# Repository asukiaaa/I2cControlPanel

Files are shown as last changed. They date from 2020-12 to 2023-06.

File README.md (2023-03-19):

# I2cControlPanel

A wired control panel.

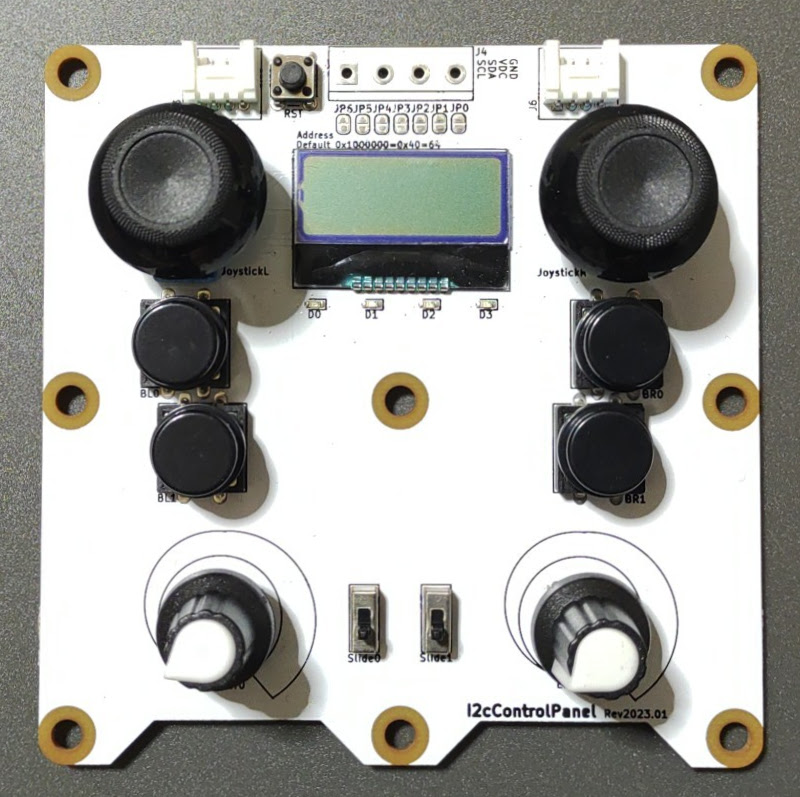
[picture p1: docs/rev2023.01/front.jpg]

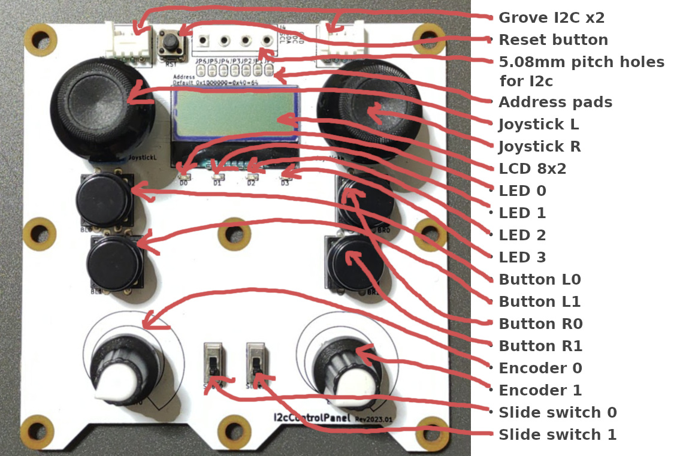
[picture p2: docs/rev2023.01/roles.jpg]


# Where to buy

- [I2cControlPanel | スイッチサイエンス](https://www.switch-science.com/catalog/6824/)

# Library
[I2cControlPanel_asukiaaa](https://github.com/asukiaaa/I2cControlPanel_asukiaaa)

# Components

- [ATmega328PB-MU](https://www.digikey.jp/product-detail/ja/microchip-technology/ATMEGA328PB-MUR/ATMEGA328PB-MURCT-ND/5722708)
- [PS4 joy stick](https://ja.aliexpress.com/item/1005001729380060.html)
- [PS4 joy stick cap](https://ja.aliexpress.com/item/32964247181.html)
- [THT encoder](https://ja.aliexpress.com/item/1005001556801559.html)
- [Switch 12mm black](https://akizukidenshi.com/catalog/g/gP-09826/)
- [LCD 8x2](https://akizukidenshi.com/catalog/g/gP-06669/)
- [Slide switch](https://akizukidenshi.com/catalog/g/gP-12723/)
- [3V3 regulator](https://akizukidenshi.com/catalog/g/gI-10675/)
- [LED 0603 green](https://akizukidenshi.com/catalog/g/gI-06417/)
- [0.47uf 0402](https://akizukidenshi.com/catalog/g/gP-07504/)
- [0.01uf 0603](https://akizukidenshi.com/catalog/g/gP-13387/)
- 0.1uf 0603
- [Diode array](https://www.digikey.jp/product-detail/ja/toshiba-semiconductor-and-storage/1SS309-TE85L-F/1SS309-TE85LF-CT-ND/4304019)
- 10k 0603

# Old components

- [Panel mount encoder](https://ja.aliexpress.com/item/32783863247.html)
- [Low height joystick](https://ja.aliexpress.com/item/4000540937190.html)
- [Low height joystick cap](https://ja.aliexpress.com/item/33035062962.html)
- [Diode](https://akizukidenshi.com/catalog/g/gI-06467/)

# License

MIT

# References

- [エンコーダー（可変抵抗）が付いた有線コントローラーを作ってみた](https://asukiaaa.blogspot.com/2020/11/i2c-control-panel.html)
- [WiredController](https://github.com/asukiaaa/WiredControllerPcb)

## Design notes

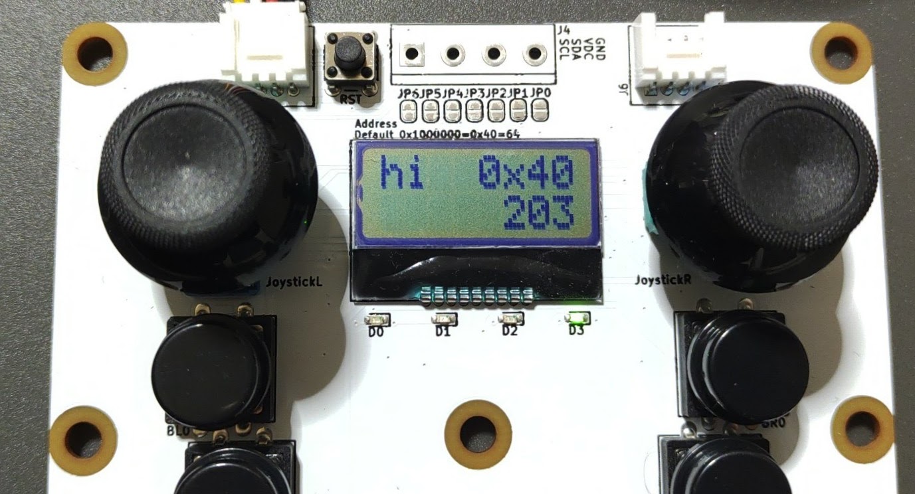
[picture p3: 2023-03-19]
docs/rev2023.01/lcd_and_leds.jpg

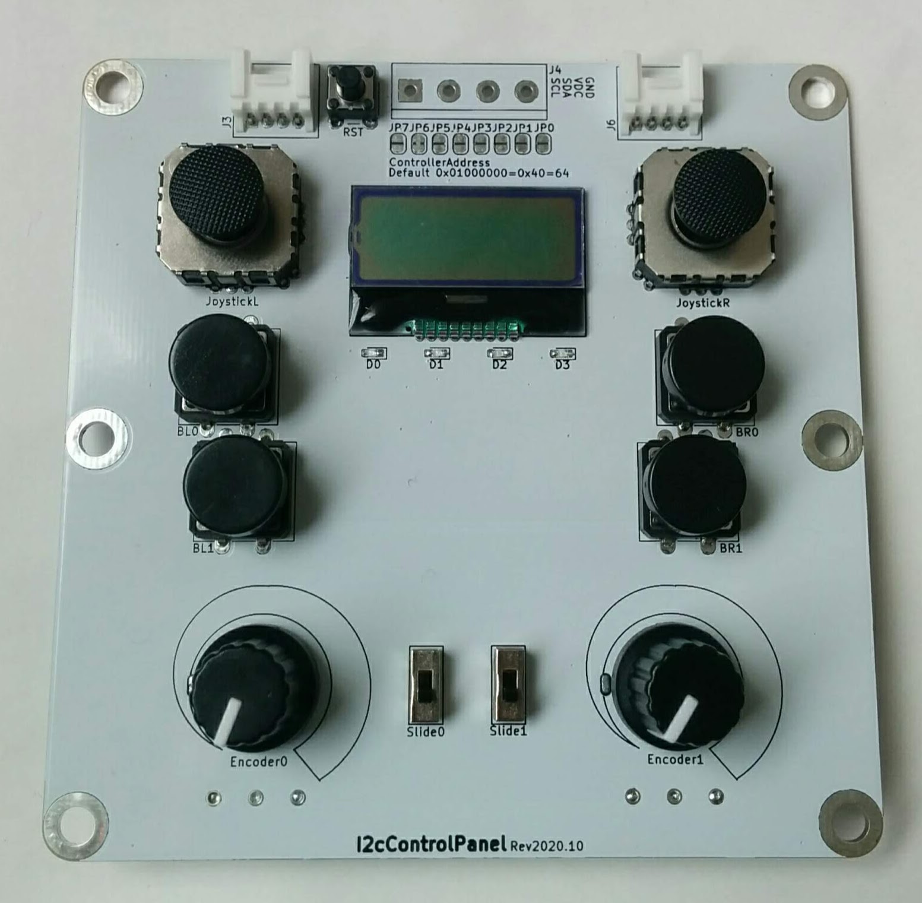
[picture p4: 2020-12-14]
docs/rev2020.10/I2cControlPanel.jpg

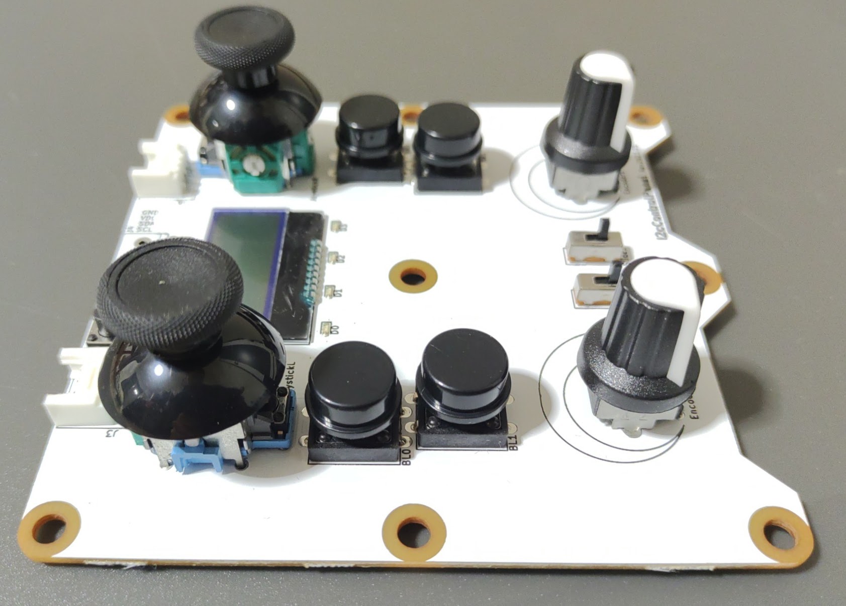
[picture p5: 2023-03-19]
docs/rev2023.01/side_view.jpg

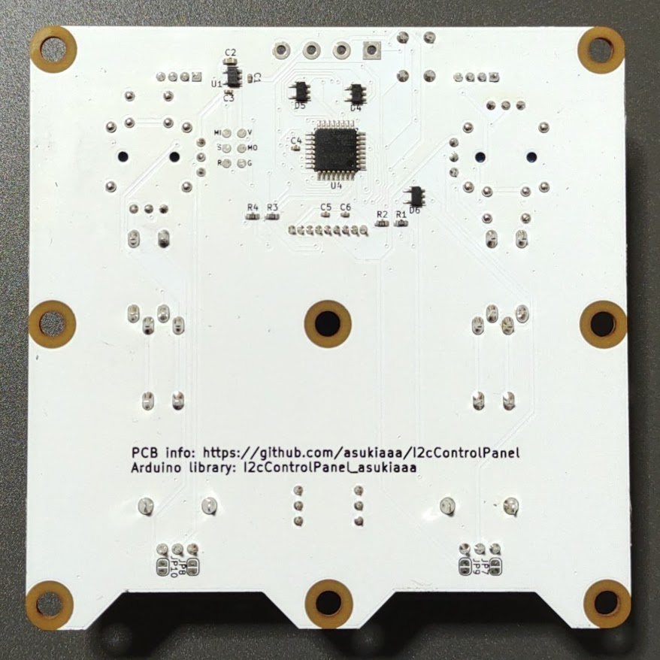
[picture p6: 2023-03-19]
docs/rev2023.01/back.jpg

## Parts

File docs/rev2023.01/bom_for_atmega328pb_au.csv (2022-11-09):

Reference | Quantity | Value | Footprint | url | memo
BL0 BR0 BL1 BR1 | 4 | Push switch 12mm black | footprints:SW_Center_PUSH-12mm |  | 12mm black
C2 | 1 | 10n | Capacitor_SMD:C_0603_1608Metric |  | 0.01uf 0603inch more than 10V. I don’t mind vendor
C3 | 1 | 0.47u | Capacitor_SMD:C_0402_1005Metric |  | 0.47uf 0402inch more than 10V. I don’t mind vendor
C1 C4 C5 C6 | 4 | 0.1u | Capacitor_SMD:C_0402_1005Metric |  | 0.1uf 0402inch more than 10V. I don’t mind vendor
D0 D1 D2 D3 | 4 | LED green 0603 inch | Diode_SMD:D_0603_1608Metric_Pad1.05x0.95mm_HandSolder | https://akizukidenshi.com/catalog/g/gI-06417/
D4 D5 D6 | 3 | 1SS309 | asukiaaa-kicad-footprints:SC-74-5_1.6x2.9mm_P0.95mm | https://www.digikey.jp/product-detail/ja/toshiba-semiconductor-and-storage/1SS309-TE85L-F/1SS309-TE85LF-CT-ND/4304019
Encoder0 Encoder1 | 2 | Encoder 10k | asukiaaa-kicad-footprints:RoteryEncoderWithPowerLabel | https://ja.aliexpress.com/item/1005001556801559.html
J1 J5 | 1 | Joystick | asukiaaa-kicad-footprints:PS4tJoystick | https://ja.aliexpress.com/item/1005001729380060.html
J3 J6 | 2 | Conn_01x04 | footprints:NS-Tech_Grove_1x04_P2mm_Horizontal | https://www.seeedstudio.com/Grove-Universal-4-pin-connector-90-10-PCs.html | Grove horizontal connector
R1 R2 R3 R4 | 4 | 100k | Resistor_SMD:R_0603_1608Metric |  | 100k 0603inch. I don’t mind vendor
SW6 | 1 | Push switch 6mm black | Button_Switch_THT:SW_PUSH_6mm |  | 6mm black
Slide0 Slide1 | 2 | SlideSwitch | asukiaaa-kicad-footprints:SlideSwitch_SS12D01G4_2posi_1line | https://akizukidenshi.com/catalog/g/gP-12723/
U1 | 1 | NJM12888F33 | Package_TO_SOT_SMD:SOT-23-5 | https://akizukidenshi.com/catalog/g/gI-10675/
U4 | 1 | ATmega328PB-A | asukiaaa-kicad-footprints:TQFP-32_7x7mm_P0.8mm_short_inner | https://www.lcsc.com/product-detail/Microcontroller-Units-MCUs-MPUs-SOCs_Microchip-Tech-ATMEGA328PB-AU_C132230.html
U3 | 1 | AQM0802 | asukiaaa-kicad-footprints:AQM0802A-RN-GBW | https://akizukidenshi.com/catalog/g/gP-06669/

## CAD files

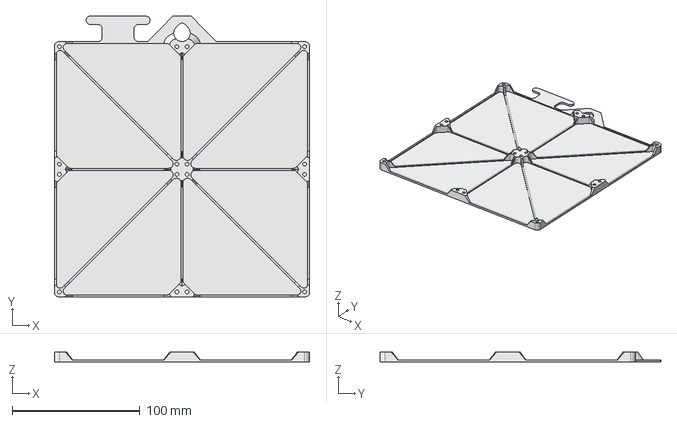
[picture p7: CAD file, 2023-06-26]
models/frame_2x2/frame_2x2.FCStd
200.0 x 220.0 x 8.00 mm

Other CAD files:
models/frame_2x2/frame_2x2.stl

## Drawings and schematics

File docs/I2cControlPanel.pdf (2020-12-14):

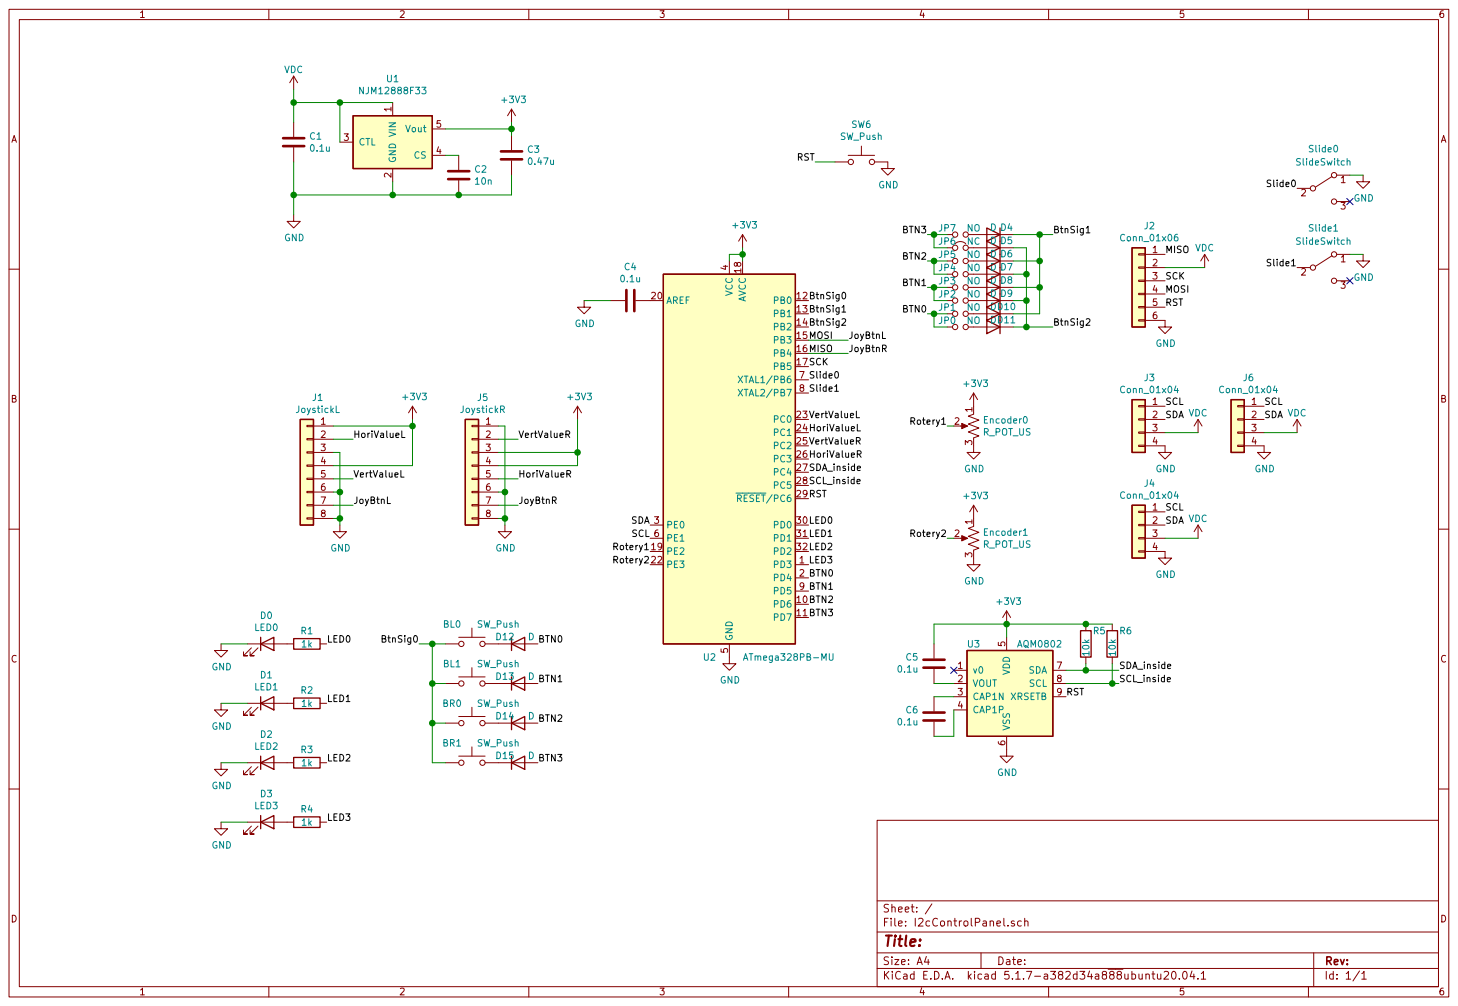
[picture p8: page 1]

Id: 1/1 Title: File: I2cControlPanel.sch Sheet: / R3

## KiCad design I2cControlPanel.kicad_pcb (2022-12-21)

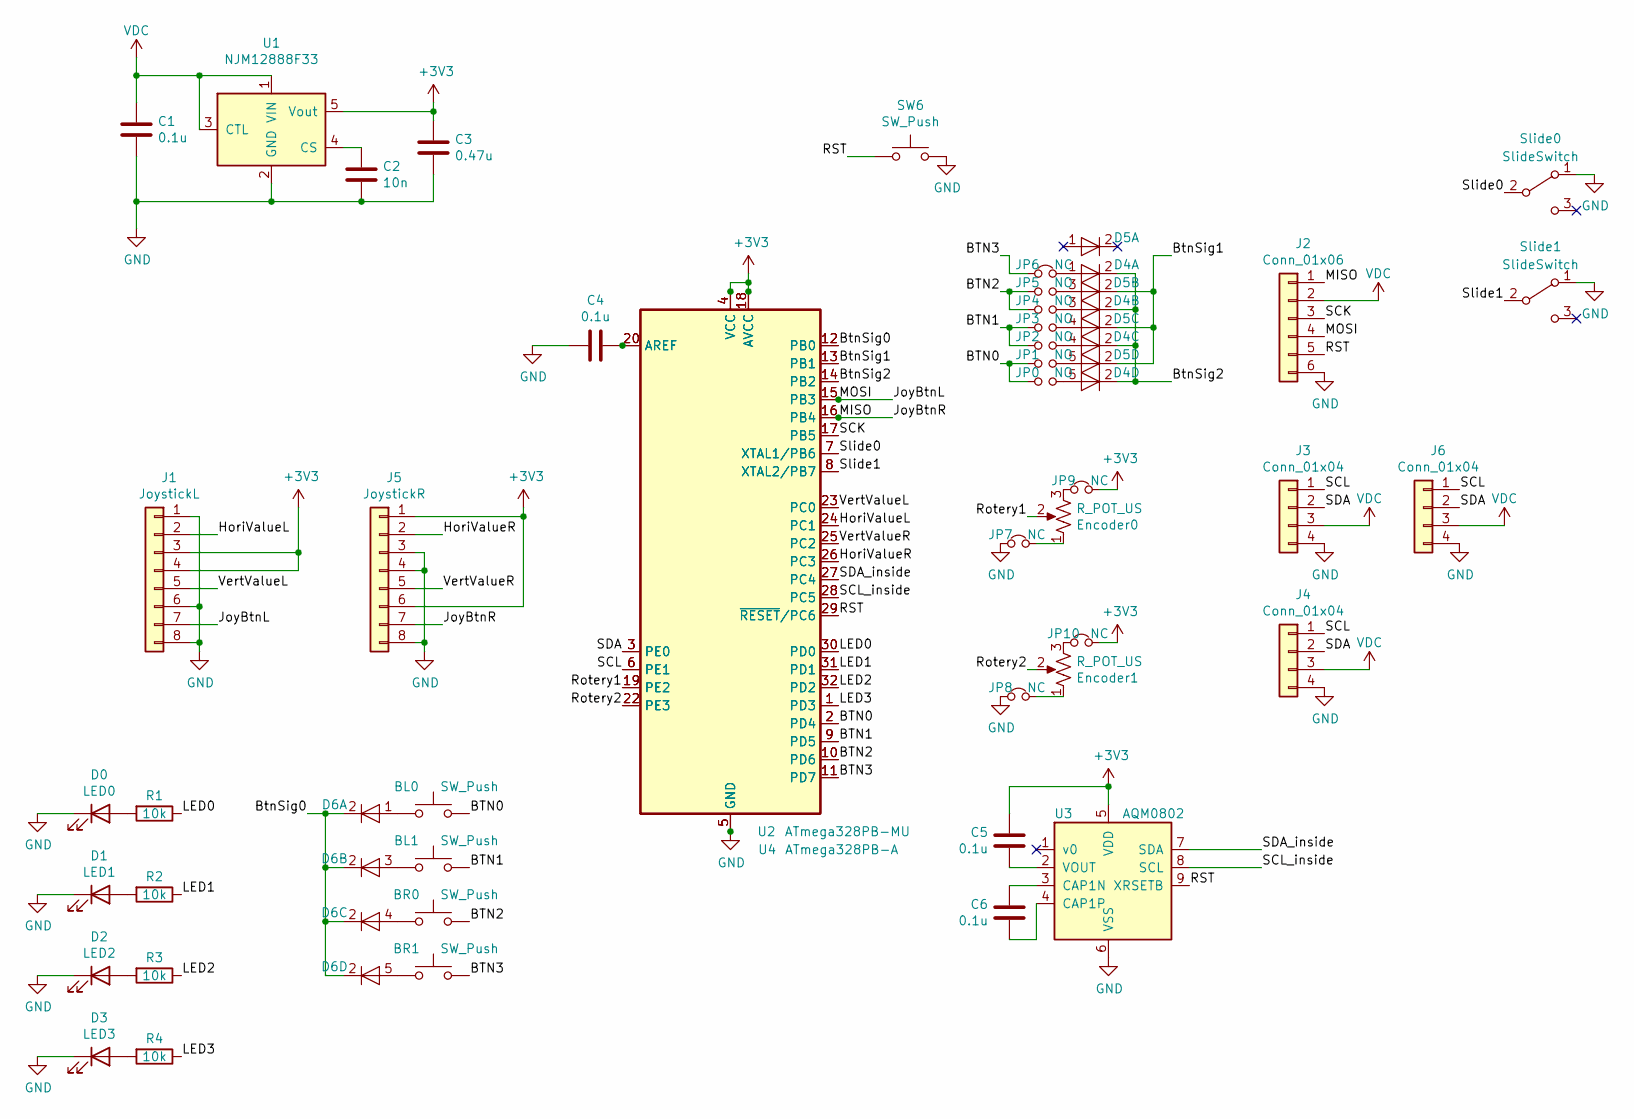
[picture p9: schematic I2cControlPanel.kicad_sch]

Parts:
BL0, BL1: SW_Push; SW_Center_PUSH-12mm
BR0, BR1: SW_Push; SW_Center_PUSH-12mm
C1, C4, C5, C6: 0.1u; C_0402_1005Metric
C2: 10n; C_0603_1608Metric
C3: 0.47u; C_0402_1005Metric
D0: LED0; D_0603_1608Metric_Pad1.05x0.95mm_HandSolder
D1: LED1; D_0603_1608Metric_Pad1.05x0.95mm_HandSolder
D2: LED2; D_0603_1608Metric_Pad1.05x0.95mm_HandSolder
D3: LED3; D_0603_1608Metric_Pad1.05x0.95mm_HandSolder
D4, D5, D6: 1SS309; SC-74-5_1.6x2.9mm_P0.95mm
Encoder0, Encoder1: R_POT_US; RoteryEncoderWithPowerLabel
J1: JoystickL; PS4tJoystick
J2: Conn_01x06; 2x03_P2.54mm_Pads
J3, J6: Conn_01x04; NS-Tech_Grove_1x04_P2mm_Horizontal
J4: Conn_01x04; TerminalBlock_bornier-4_P5.08mm
J5: JoystickR; PS4tJoystick
JP0, JP1, JP2, JP3, JP4, JP5: NO; SolderJumper-2_P1.3mm_Open_RoundedPad1.0x1.5mm
JP6, JP7, JP8, JP9, JP10: NC; SolderJumper-2_P1.3mm_Bridged_RoundedPad1.0x1.5mm
R1, R2, R3, R4: 10k; R_0603_1608Metric
SW6: SW_Push; SW_PUSH_6mm
Slide0, Slide1: SlideSwitch; SlideSwitch_SS12D01G4_2posi_1line
U1: NJM12888F33; SOT-23-5
U2: ATmega328PB-MU; QFN-32-1EP_5x5mm_P0.5mm_EP3.1x3.1mm
U3: AQM0802; AQM0802A-RN-GBW
U4: ATmega328PB-A; TQFP-32_7x7mm_P0.8mm_short_inner

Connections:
+3V3: C3.1, C5.2, J1.3, J1.4, J5.1, J5.6, JP9.2, JP10.2, U1.5 (Vout), U2.4 (VCC), U2.18 (AVCC), U3.5 (VDD), U4.4 (VCC), U4.18 (AVCC)
/BTN0: BL0.2, JP0.1, JP1.1, U2.2 (PD4), U4.2 (PD4)
/BTN1: BL1.2, JP2.1, JP3.1, U2.9 (PD5), U4.9 (PD5)
/BTN2: BR0.2, JP4.1, JP5.1, U2.10 (PD6), U4.10 (PD6)
/BTN3: BR1.2, JP6.1, U2.11 (PD7), U4.11 (PD7)
/BtnSig0: D6.2, U2.12 (PB0), U4.12 (PB0)
/BtnSig1: D5.2, U2.13 (PB1), U4.13 (PB1)
/BtnSig2: D4.2, U2.14 (PB2), U4.14 (PB2)
/HoriValueL: J1.2, U2.24 (PC1), U4.24 (PC1)
/HoriValueR: J5.2, U2.26 (PC3), U4.26 (PC3)
/JoyBtnL: J1.7, J2.4, U2.15 (PB3), U4.15 (PB3)
/JoyBtnR: J2.1, J5.7, U2.16 (PB4), U4.16 (PB4)
/LED0: R1.1, U2.30 (PD0), U4.30 (PD0)
/LED1: R2.1, U2.31 (PD1), U4.31 (PD1)
/LED2: R3.1, U2.32 (PD2), U4.32 (PD2)
/LED3: R4.1, U2.1 (PD3), U4.1 (PD3)
/RST: J2.5, SW6.1, U2.29 (~RESET/PC6), U3.9 (XRSETB), U4.29 (~RESET/PC6)
/Rotery1: Encoder0.2, U2.19 (PE2), U4.19 (PE2)
/Rotery2: Encoder1.2, U2.22 (PE3), U4.22 (PE3)
/SCK: J2.3, U2.17 (PB5), U4.17 (PB5)
/SCL: J3.1, J4.1, J6.1, U2.6 (PE1), U4.6 (PE1)
/SCL_inside: U2.28 (PC5), U3.8 (SCL), U4.28 (PC5)
/SDA: J3.2, J4.2, J6.2, U2.3 (PE0), U4.3 (PE0)
/SDA_inside: U2.27 (PC4), U3.7 (SDA), U4.27 (PC4)
/Slide0: Slide0.2 (B), U2.7 (XTAL1/PB6), U4.7 (XTAL1/PB6)
/Slide1: Slide1.2 (B), U2.8 (XTAL2/PB7), U4.8 (XTAL2/PB7)
/VertValueL: J1.5, U2.23 (PC0), U4.23 (PC0)
/VertValueR: J5.5, U2.25 (PC2), U4.25 (PC2)
GND: C1.2, C2.2, C3.2, C4.1, D0.1 (K), D1.1 (K), D2.1 (K), D3.1 (K), J1.1, J1.6, J1.8, J2.6, J3.4, J4.4, J5.3, J5.4, J5.8, J6.4, JP7.1, JP8.1, SW6.2, Slide0.1 (A), Slide1.1 (A), U1.2 (GND), U2.5 (GND), U2.21 (GND), U2.33 (GND), U3.6 (VSS), U4.5 (GND), U4.21 (GND)
unnamed: BL0.1, D6.1
unnamed: BL1.1, D6.3
unnamed: BR0.1, D6.4
unnamed: BR1.1, D6.5
unnamed: C2.1, U1.4 (CS)
unnamed: C4.2, U2.20 (AREF), U4.20 (AREF)
unnamed: C5.1, U3.2 (VOUT)
unnamed: C6.1, U3.4 (CAP1P)
unnamed: C6.2, U3.3 (CAP1N)
unnamed: D0.2 (A), R1.2
unnamed: D1.2 (A), R2.2
unnamed: D2.2 (A), R3.2
unnamed: D3.2 (A), R4.2
unnamed: D4.1, JP6.2
unnamed: D4.3, JP4.2
unnamed: D4.4, JP2.2
unnamed: D4.5, JP0.2
unnamed: D5.3, JP5.2
unnamed: D5.4, JP3.2
unnamed: D5.5, JP1.2
unnamed: Encoder0.1, JP7.2
unnamed: Encoder0.3, JP9.1
unnamed: Encoder1.1, JP8.2
unnamed: Encoder1.3, JP10.1
VDC: C1.1, J2.2, J3.3, J4.3, J6.3, U1.1 (VIN), U1.3 (CTL)

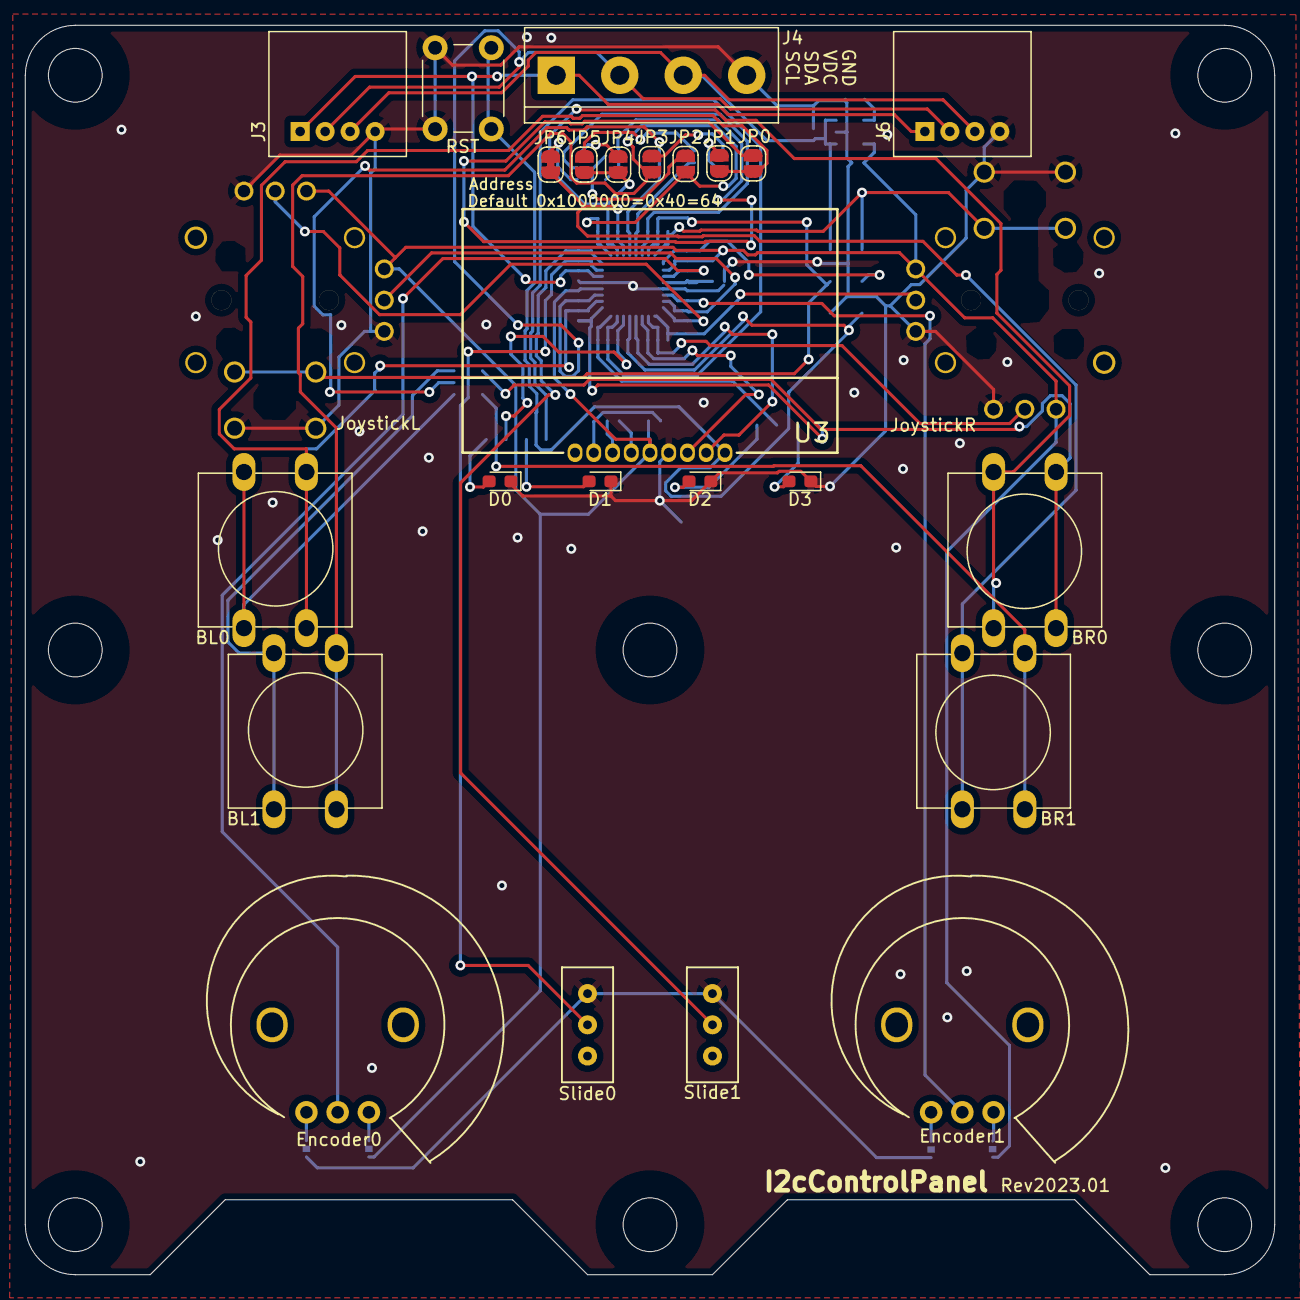
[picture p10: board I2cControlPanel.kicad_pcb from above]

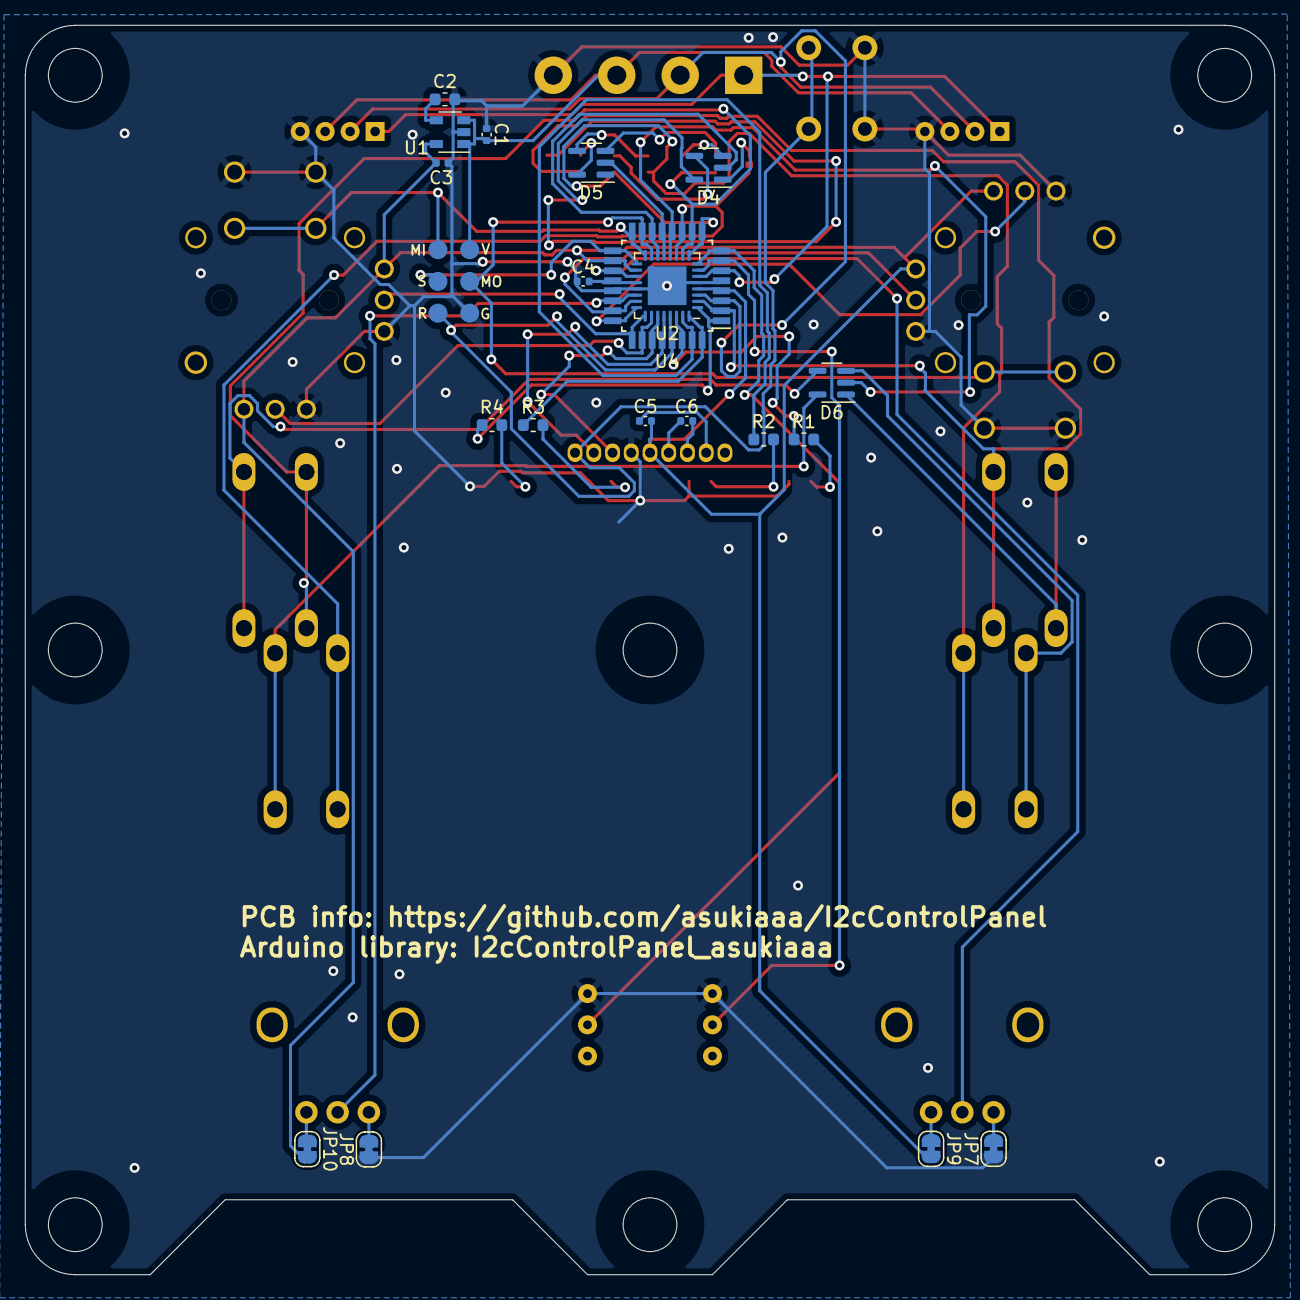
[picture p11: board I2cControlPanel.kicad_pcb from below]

Board: 2 copper layers, 100.0 x 100.0 mm, 55 parts (21 on the bottom side), 54 nets.

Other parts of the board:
REF1, REF2, REF3, REF4, REF5, REF6, REF7, REF8: MountingHole_4.3mm_M4_bare

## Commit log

2020-08-14 Update for rev 2020.08
    [I2cControlPanel.kicad_pcb, I2cControlPanel.sch]
2020-08-14 Replace gnd and 3v3 for right joy stick
    [I2cControlPanel.kicad_pcb, I2cControlPanel.sch]
2020-08-23 Update footprint of volume
    [I2cControlPanel.kicad_pcb]
2020-08-29 Correct button line for address pads
    [I2cControlPanel.kicad_pcb, I2cControlPanel.sch]
2020-09-03 Update slide switch position and labels for each buttons
    [I2cControlPanel.kicad_pcb, I2cControlPanel.sch]
2020-09-03 Update revision to 2020.08 and github url and arduino library info
    [I2cControlPanel.kicad_pcb]
2020-09-19 Change pin assign for left joy hori and vert
    [I2cControlPanel.sch]
2020-09-20 Update hole position of volume
    [I2cControlPanel.kicad_pcb]
2020-09-24 Remove R7 resistor
    [I2cControlPanel.sch]
2020-09-26 Replace vert and hori for joy
    [I2cControlPanel.kicad_pcb, I2cControlPanel.sch]
2020-09-26 Change pad for diode
    [I2cControlPanel.kicad_pcb, I2cControlPanel.sch]
2020-09-26 Update pad of led for soldering by hand
    [I2cControlPanel.kicad_pcb, I2cControlPanel.sch]
2020-09-26 Change slide switch
    [I2cControlPanel.kicad_pcb, I2cControlPanel.sch]
2020-09-26 Update revision to 2020.10
    [I2cControlPanel.kicad_pcb]
2020-11-29 Add size info to pcb
    [I2cControlPanel.kicad_pcb]
2020-12-14 Remove redundant bom files
    [bom_for_elecrow.csv, bom_for_fusionPCB.csv]
2020-12-14 Plot schematic as pdf
    [I2cControlPanel.sch]
2021-03-12 Use diode array and add mounting holes as Rev2021.03
    [I2cControlPanel.kicad_pcb, I2cControlPanel.sch]
2021-04-06 Change joystick for ps4 type
    [I2cControlPanel.sch]
2021-04-06 Assign 0402 condensor for 0.1uf
    [I2cControlPanel.sch]
2021-04-06 Update pcb for Rev2021.04
    [I2cControlPanel.kicad_pcb]
2021-04-25 Change position of c1 label
    [I2cControlPanel.kicad_pcb]
2021-04-29 Change rotery encoder and remove pull up for internal i2c
    [I2cControlPanel.kicad_pcb, I2cControlPanel.sch]
2021-04-29 Update revision to 2021.05
    [I2cControlPanel.kicad_pcb]
2021-10-01 Create bom.csv and update components on readme
    [bom.csv]
2022-06-27 Update for KiCad6
    [I2cControlPanel.kicad_pcb, I2cControlPanel.kicad_sch, I2cControlPanel.sch]
2022-06-27 Assign asukiaaa-kicad- symbols and footprints
    [I2cControlPanel.kicad_pcb, I2cControlPanel.kicad_sch, bom.csv]
2022-06-27 Change mounting hole as bare
    [I2cControlPanel.kicad_pcb]
2022-06-27 Update revision as 2022.07
    [I2cControlPanel.kicad_pcb]
2022-07-27 Joint missing BtnSig1 line on pcb
    [I2cControlPanel.kicad_pcb]
2022-11-09 Add A package for ATmega328PB
    [I2cControlPanel.kicad_pcb, I2cControlPanel.kicad_sch]
2022-11-09 Add bom for a package for atmega328pb
    [bom_for_atmega328pb_au.csv]
2022-12-21 Add bottom space as rev2023.01
    [I2cControlPanel.kicad_pcb]
2023-03-19 Use photo of rev2023.01 on top
    [bom.csv, bom_for_atmega328pb_au.csv]
2023-03-19 Add a link for arduino library
2023-06-26 Add frame_2x2
    [frame_2x2.FCStd, frame_2x2.stl]
